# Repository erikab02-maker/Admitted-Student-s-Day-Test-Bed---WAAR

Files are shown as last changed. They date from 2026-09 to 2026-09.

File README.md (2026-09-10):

The purpose of the Admitted Student’s Day testbed was to evaluate the stability and performance of the inner-loop flight controller under control conditions for Admitted Students Day. This would allow students to visually see how the PID controller works to stabilize the drone when manual torque is applied. Under successful testing conditions, the drone would demonstrate its ability to self-stabilize when subjected to disturbances meant to simulate disturbances from gusts of wind. The project involved connecting the drone to a PVC pipe which was mounted between two vertical stands. The pipe could be torqued gently, rotating the drone and simulating wind from two directions.

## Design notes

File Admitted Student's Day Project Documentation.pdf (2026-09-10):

# WAAR Test Bed for Admitted Students Day

# Overview

Test Name: Test Bed or Gyroscope for Admitted Students Day

Subsystem: Hardware

Author: Erika Berreth
Date Executed: 4/3/26
Location: University of Washington
Status: Completed
Credit: The attachment of the drone to the PVC pipe was designed by Diego Heredia.

## Objective

The purpose of this testbed is to evaluate the stability and performance of the inner-loop flight controller under control conditions for Admitted Students Day. This will allow students to visually see how the PID controller works to stabilize the drone when manual torque is applied.

## Requirements

Requirement | Value | Notes | Status
Degrees of Freedom | ≥ 1 DOF (2 DOF target) | Pitch required; roll preferred for coupling effects | MET
Safety Requirement | The system shall include propeller guards or equivalent protective shielding | Prevent user injury and damage during operation | MET (NOTE: we will just not have kids touch the drone).

Disturbance
Rejection

The testbed shall allow
manual disturbance

Enables evaluation of
disturbance rejection

MET

WAAR Test Bed for Admitted Students Day | 1

inputs (e.g., external
force applied by hand)
Mounting | The drone shall be rigidly mounted and capable of withstanding ≥ 1.5 kg vertical thrust force without structural failure | Ensures structural integrity under maximum thrust | MET
Cost | The testbed shall cost less than $80 | | MET

## Equipment and Setup

Equipment:

PLA for the 3D printer ( ~ 600 grams)

5 ft of PVC Pipe

Wooden plank (~ 4 in x 8 in)

8 screws

Electric Drill + drill bits

Software:

SolidWorks

Design Setup:

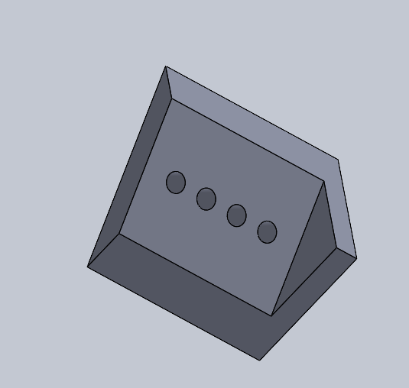
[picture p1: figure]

Step 1: Design the side supports in SolidWorks to have a triangular base (for better support) and a trapezoid extension with four holes in the side. See image below for a visual representation.

Tip:

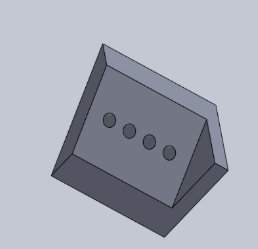
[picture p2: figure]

Measure the PVC pipe’s cross-sectional dimensions. It was around 0.75 inches for the initial setup with an added tolerance of 0.15. If necessary, cut it to 1.5 inches in length. The height of the structure was around 8.5 inches.

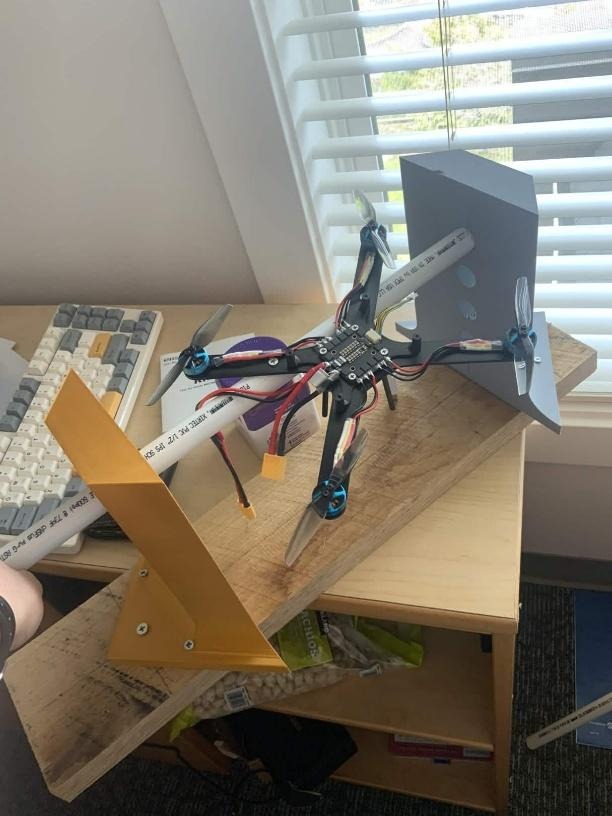
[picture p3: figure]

Step 2: Print the side supports with a 3D printer and the PLA.
Step 3: Take the electric drill and with the drill bit drill holes into the plank at three locations that when connected form an isosceles triangle. Then, drill in the screws to attach the side supports to the plank.
Step 4: Drill a hold on the left and right side of the pipe that goes through the right side support. Then, drill in one screw into each hole. This will prevent the pipe from sliding out of the side supports. An image of the setup with the drone in the frame can be found below.

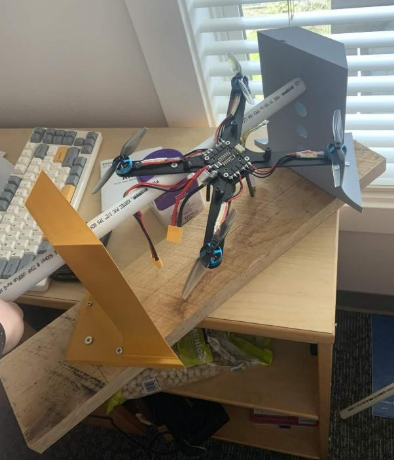
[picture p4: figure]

Tip: Make sure to have more room between the side supports than the longest dimension of the drone.

Step 5: Design the attachment from the drone to the pipe in SolidWorks so that it attaches to the battery mount at the bottom of the drone and has a hole for the PVC pipe to go through.

Tip: The goal of this component is to attach the drone to the pipe so that when someone twists the end of the pipe torque will be applied to the drone. An image of the design can be found below:

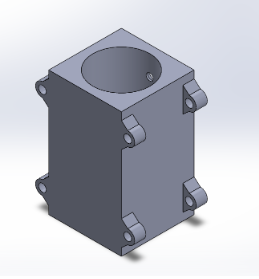
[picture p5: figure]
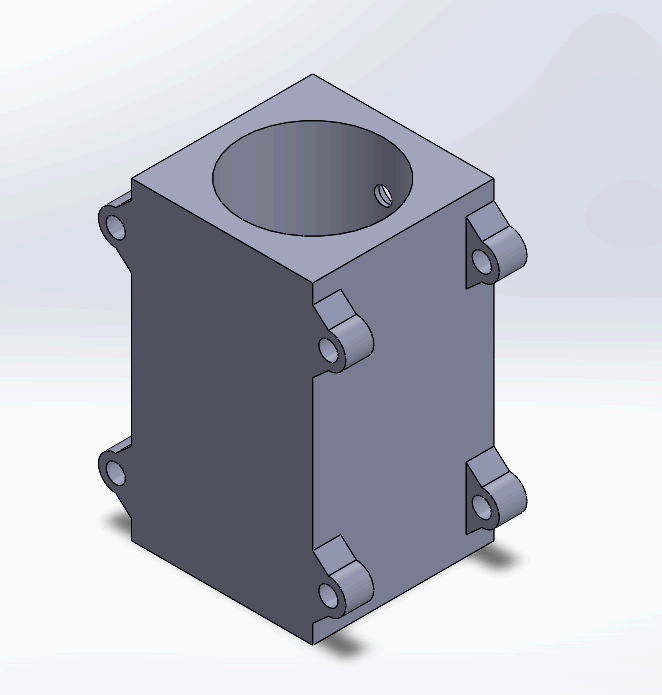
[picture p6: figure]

Step 6: Print the attachment component with the 3D printer, and use it to attach the drone to the pipe.

## Conclusion

Iterations of Design: at first the drone was designed to be connected by a string to the side supports so that it had one degree of freedom. The string would be attached to two ends of the drone frame and to the adjacent side supports so that the drone would be suspended in the air. An image of what this might have looked like can be seen below:

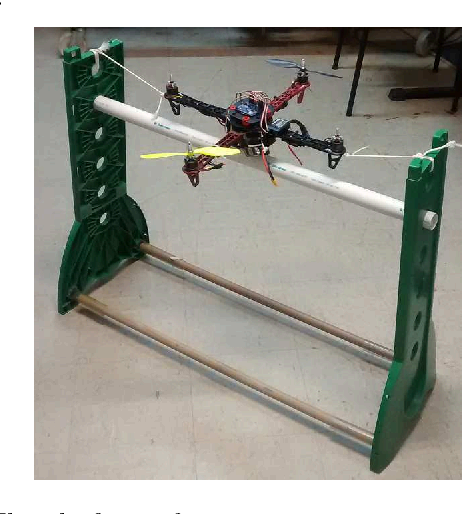
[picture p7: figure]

This didn’t work for Admitted Students Day because it changed the center of mass of the system. The second iteration of the design involved an attachment to the drone which connected the drone to the pipe so that it was underneath the drone’s center of mass and didn’t shift it.

Final Test Bed:

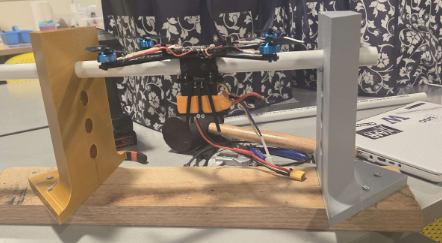
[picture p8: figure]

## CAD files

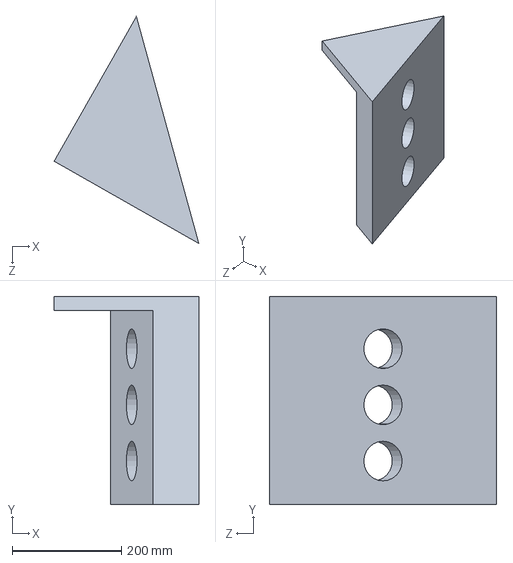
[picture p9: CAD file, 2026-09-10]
Admitted Student's Day/Side_Support_Test_Bed_1.SLDPRT
265.0 x 381.0 x 415.6 mm

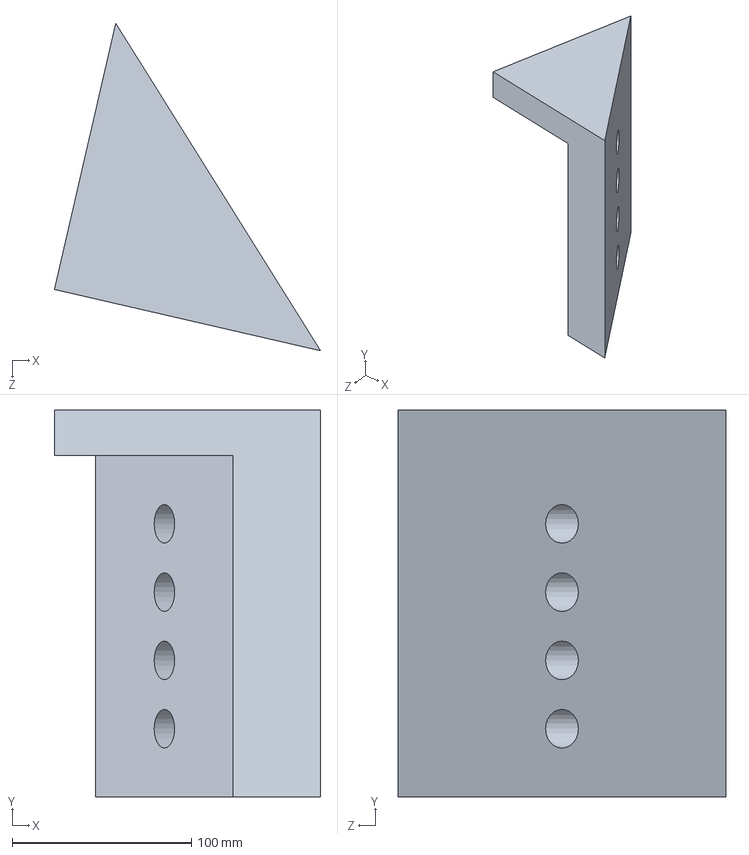
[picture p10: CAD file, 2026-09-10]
Admitted Student's Day/Side_Support_Test_Bed_2.SLDPRT
148.5 x 215.9 x 182.7 mm
